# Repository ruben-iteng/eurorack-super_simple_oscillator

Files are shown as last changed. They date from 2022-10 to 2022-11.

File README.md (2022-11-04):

<div align="center">

# eurorack-super_simple_oscillator

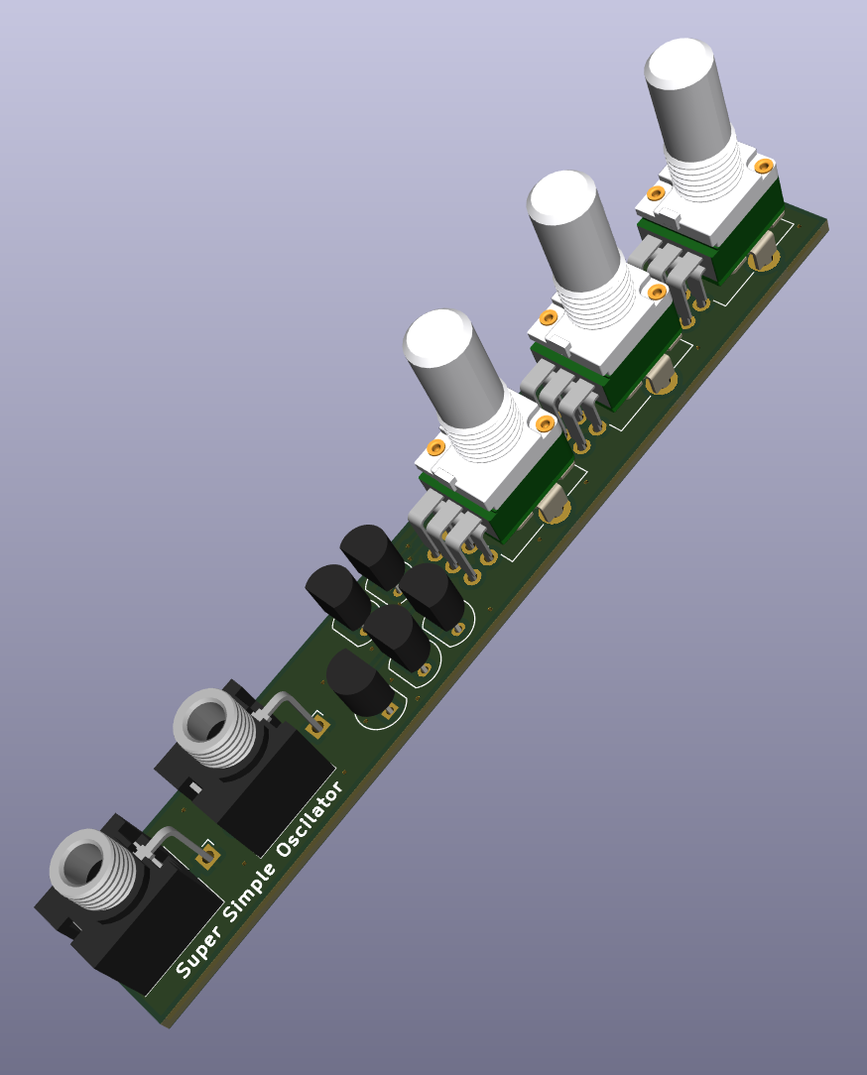
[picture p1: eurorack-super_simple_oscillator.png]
Super Simple Oscillator PCBA

<br/>

Eurorack modular synthesiser - Super Simple Oscillator

     

</div>

## About

<div align="center">
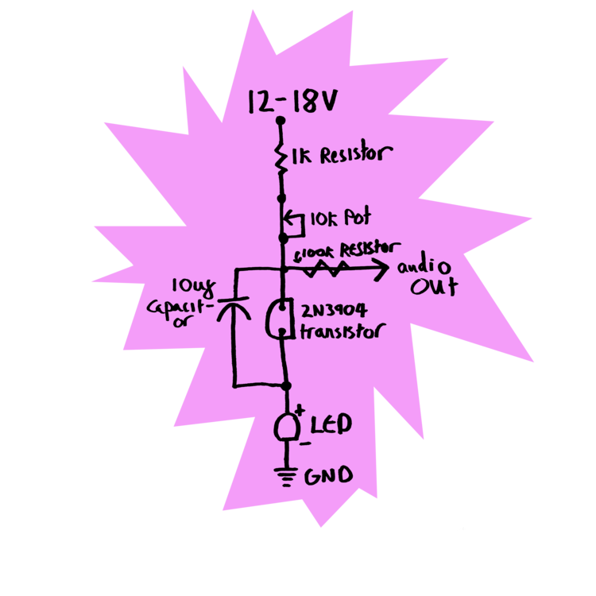
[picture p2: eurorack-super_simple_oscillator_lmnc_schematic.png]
SUPER SIMPLE OSCILLATOR SCHEMATIC, Look Mum No Computer, 05-2022

</div>

A super simple oscillator module (avalanche vco) in eurorack format based the designs of [Look Mum No Computer](https://www.lookmumnocomputer.com/projects#/simplest-oscillator) and [kassutronics](https://kassu2000.blogspot.com/2018/07/avalance-vco.html).
This project is build with the opensource EDA [faebryk](https://github.com/faebryk/faebryk).

## What can you do with this project?

You can use this project in various ways.
You can use it:

- as template for a faebryk project
- to build this VCO for your eurorack synth
- to design your own thing based on this design

## Working with the source files

See [here](./docs/development.md) for the instructions on how to install and edit this project.

## Building the SSO module

If you want to build a physical SSO eurorack module you can find the build instructions [here](./docs/build_instructions.md).

## Contibuting

If you want to share your alterations, improvements, or add bugfixes to this project, please take a look at the [contributing guidelines](./docs/CONTRIBUTING.md).

## Community Support

Community support is provided via Discord; see the Resources below for details.

### Resources

- Source Code: [https://github.com/ruben-iteng/eurorack-super_simple_oscillator](https://github.com/ruben-iteng/eurorack-super_simple_oscillator)
- Chat: Real-time chat happens in faebryk's Discord Server (chit-chat room for now). Use this Discord [Invite](https://discord.gg/95jYuPmnUW) to register
- Issues: [https://github.com/ruben-iteng/eurorack-super_simple_oscillator/issues](https://github.com/ruben-iteng/eurorack-super_simple_oscillator/issues)

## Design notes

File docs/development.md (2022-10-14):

# Working with the Super Simple Oscillator source

## Project structure

```markdown
📦eurorack-super_simple_oscillator
 ┣ 📂build `Here you can find the "usefull" files after building this project localy`
 ┃ ┣ 📂faebryk
 ┃ ┣ 📂kicad
 ┣ 📂docs `Project documentation is placed in this folder`
 ┣ 📂source
 ┃ ┣ 📂faebryk
 ┃ ┃ ┣ 📂library
 ┃ ┃ ┃ ┣ 📂library
 ┃ ┃ ┃ ┃ ┗ 📜components.py `In this file you can put the components that are not in the standard faebryk library`
 ┃ ┃ ┣ 📂modules
 ┃ ┃ ┗ 📜main.py `This is the main faberyk file of this project. Any changes should be made here`
 ┃ ┣ 📂kicad `KiCad project files`
 ┃ ┃ ┗ 📂main
 ┃ ┃ ┃ ┣ 📜main.kicad_pcb
 ┃ ┃ ┃ ┣ 📜main.kicad_pro
 ┃ ┃ ┃ ┣ 📜main.kicad_sch
 ┣ 📜.gitignore
 ┣ 📜eurorack-super_simple_oscillator.png
 ┣ 📜LICENSE
 ┣ 📜README.md `Project "homepage"`
 ┗ 📜requirements.txt `Required python/pip packages`
```

## Prerequisites

To start working on this project you will need the following.

### Step 1

Install the following programs:

- [Visual Code Studio](https://code.visualstudio.com/)
- [Python 3](https://www.python.org/) (add to PATH)
- [KiCad 6](https://www.kicad.org/)
- [git](https://git-scm.com/)

### Step 2

Clone this repository and install the requirements

```bash
git clone git@github.com:ruben-iteng/eurorack-super_simple_oscillator.git
```

```bash
cd eurorack-super_simple_oscillator
pip install -r requirements.txt
```

### Step 3

Run the project to see if everything is installed correctly

```bash
python3 ./source/main.py
```

This should output a netlist file in the `./build/faebryk/netlist/` folder.

### Step 4

Check if KiCad works

Open the `./source/kicad/main.prj` file in KiCad.

## Editing the project

The file you will work with most is the `./source/faebryk/main.py`. Here you describe your design in faebryk.

If you want to create your own components, traits or modules specific to this project you can place them in `./source/faebryk/library/<thing you want to add>`.

The PCB layout can be eddited in KiCad 6 by edditing the `./souce/kicad/main/main.kicad_pcb` file. If you changed anything in the faebryk source, you have to re-import the netlist into KiCad like so:

- `file > import > netlist`
- Select the file `./build/faebryk/faebryk.net`
- Press `Load and Test Netlist`
- If there are no errors, press `Update PCB`

## Running the project

To run the project and output the build files do as follow:

```bash
python ./source/faebryk/main.py
```

The output files will be in `./build/faebryk/`

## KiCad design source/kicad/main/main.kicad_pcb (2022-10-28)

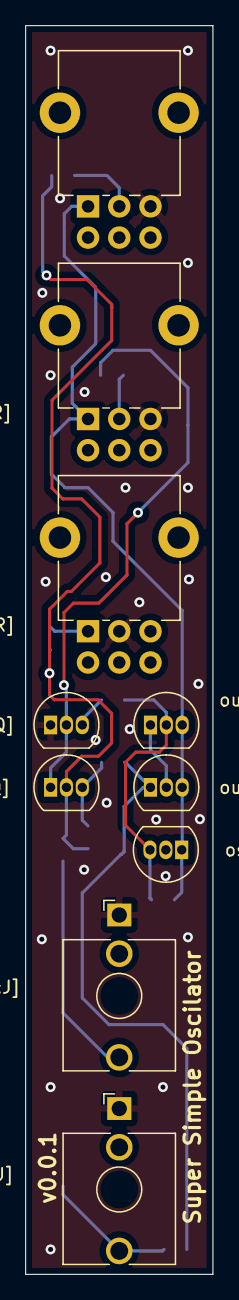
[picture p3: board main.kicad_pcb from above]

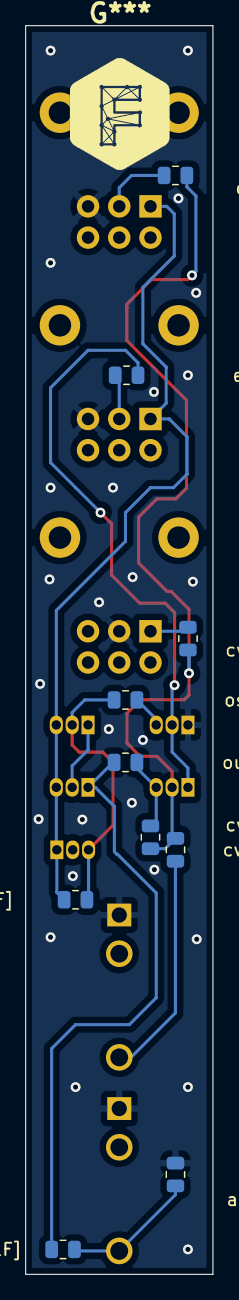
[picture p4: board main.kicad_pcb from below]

Board: 2 copper layers, 15.0 x 100.0 mm, 20 parts (10 on the bottom side), 14 nets.

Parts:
audio_output.ac_coupling_capacitor[Capacitor:9.999999999999998µF]: 9.999999999999998µF; R_0805_2012Metric
audio_output.jack[AudioJack2_Ground:J]: J; Jack_3.5mm_QingPu_WQP-PJ398SM_Vertical_CircularHoles
audio_output.pull_down_resistor[Resistor:10KΩ]: 10KΩ; R_0805_2012Metric
cv_input.freq_devider_mix_resistor[Resistor:150KΩ]: 150KΩ; R_0805_2012Metric
cv_input.frequency_control_potentiometer[Potentiometer:R], cv_input.voct_scale_trimmer[Potentiometer:R]: R; Potentiometer_Alpha_RD902F-40-00D_Dual_Vertical_CircularHol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
cv_input.input_impendace_resistor[Resistor:100KΩ]: 100KΩ; R_0805_2012Metric
cv_input.input_jack[AudioJack2_Ground:J]: J; Jack_3.5mm_QingPu_WQP-PJ398SM_Vertical_CircularHoles
cv_input.negative_bias_resistor[Resistor:220KΩ]: 220KΩ; R_0805_2012Metric
cv_input.voct_min_resistor[Resistor:1.0KΩ]: 1.0KΩ; R_0805_2012Metric
expo_converter.buffer[_2N3906:Q], expo_converter.current_sink[_2N3904:Q]: Q; TO-92_Inline
expo_converter.frequency_offset_current_min_resistor[Resistor:100KΩ]: 100KΩ; R_0805_2012Metric
expo_converter.frequency_offset_trimmer[Potentiometer:R]: R; Potentiometer_Alpha_RD902F-40-00D_Dual_Vertical_CircularHol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
osc_core.charge_capacitor[Capacitor:10.0µF]: 10.0µF; R_0805_2012Metric
osc_core.current_limiting_resistor[Resistor:1KΩ]: 1KΩ; R_0805_2012Metric
osc_core.reverse_avalanche_transistor[_2N3904:Q]: Q; TO-92_Inline
output_buffer.current_limiting_resistor[Resistor:10KΩ]: 10KΩ; R_0805_2012Metric
output_buffer.stages[0][_2N3904:Q], output_buffer.stages[1][_2N3904:Q]: Q; TO-92_Inline

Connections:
[Kassutronics_Avalance_VCO:virt]-cv_input[cv_input:virt]:2-cv_input.voct_scale_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: audio_output.jack[AudioJack2_Ground:J].S, audio_output.pull_down_resistor[Resisto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.2, cv_input.frequency_control_potentiomete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.3, cv_input.input_jack[AudioJack2_Ground:J].S, cv_input.voct_scale_trimmer[Potentiomet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.2, expo_converter.current_sink[_2N3904:Q].1, expo_converter.frequency_offset_trimmer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.3
[Kassutronics_Avalance_VCO:virt]:3-cv_input[cv_input:virt]:4-expo_converter[exp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: cv_input.negative_bias_resistor[Resisto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.2, expo_converter.buffer[_2N3906:Q].3, output_buffer.current_limiting_resistor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.2
audio_output.ac_coupling_capacitor[Capacitor:9.999999999999998µF]-audio_output.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: audio_output.ac_coupling_capacitor[Capa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.2, audio_output.jack[AudioJack2_Ground:J].T, audio_output.pull_down_resistor[Resisto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.1
audio_output[audio_output:virt]:2-output_buffer[output_buffer:virt]:3: audio_output.ac_coupling_capacitor[Capa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.1, output_buffer.current_limiting_resistor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.1, output_buffer.stages[1][_2N3904:Q].1
cv_input.frequency_control_potentiometer.resistors[0][Resistor:virt]-output_buf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: cv_input.frequency_control_potentiomete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.1, expo_converter.frequency_offset_trimmer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.1, osc_core.charge_capacitor[Capacitor:10.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.2, osc_core.reverse_avalanche_transistor[_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.1, output_buffer.stages[0][_2N3904:Q].3, output_buffer.stages[1][_2N3904:Q].3
cv_input.frequency_control_potentiometer.resistors[0][Resistor:virt]:2-cv_input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: cv_input.freq_devider_mix_resistor[Resi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.2, cv_input.frequency_control_potentiomete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.2
cv_input.input_jack[AudioJack2_Ground:J]-cv_input.input_impendace_resistor[Resi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: cv_input.input_impendace_resistor[Resis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.1, cv_input.input_jack[AudioJack2_Ground:J].T
cv_input.voct_scale_trimmer.resistors[0][Resistor:virt]: cv_input.voct_min_resistor[Resistor:1.0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.2, cv_input.voct_scale_trimmer[Potentiomet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.1
cv_input[cv_input:virt]-expo_converter[expo_converter:virt]: cv_input.freq_devider_mix_resistor[Resi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.1, cv_input.input_impendace_resistor[Resis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.2, cv_input.negative_bias_resistor[Resisto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.1, cv_input.voct_min_resistor[Resistor:1.0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.1, expo_converter.buffer[_2N3906:Q].2
expo_converter.frequency_offset_current_min_resistor[Resistor:100KΩ]-expo_conve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: expo_converter.buffer[_2N3906:Q].1, expo_converter.current_sink[_2N3904:Q].2, expo_converter.frequency_offset_current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.1
expo_converter.frequency_offset_trimmer.resistors[0][Resistor:virt]:2-expo_conv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: expo_converter.frequency_offset_current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.2, expo_converter.frequency_offset_trimmer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.2
osc_core[osc_core:virt]-expo_converter[expo_converter:virt]:2: expo_converter.current_sink[_2N3904:Q].3, osc_core.current_limiting_resistor[Resi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.1
osc_core[osc_core:virt]:3-output_buffer[output_buffer:virt]:4: osc_core.charge_capacitor[Capacitor:10.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.1, osc_core.current_limiting_resistor[Resi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.2, osc_core.reverse_avalanche_transistor[_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.3, output_buffer.stages[0][_2N3904:Q].2
output_buffer.stages[1][_2N3904:Q]-output_buffer.stages[0][_2N3904:Q]: output_buffer.stages[0][_2N3904:Q].1, output_buffer.stages[1][_2N3904:Q].2

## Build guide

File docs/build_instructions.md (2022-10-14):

# SSO build instructions

So you have decided to build the Super Simple Oscillator eurorack module but are questioning yourself, *"where should I start?"*.

You are in luck! :) You can start right here!

## Hardware

### PCB

The first step is to order the printed circuit boards (PCBs).

Most of the time a PCB manufacturer expexts a .zip file from you containing so called *gerber* files. These files are describing your PCB design in a way that it's understandable by the software the machines in the factory use.

The latest gerber file package can be found [here](https://github.com/ruben-iteng/eurorack-super_simple_oscillator/releases/latest) as `gerber.zip`.

See the `readme.md` file included in the realease package for specific order instructions.

Some common PCB manufacturers:

- [JLCPCB](https://jlcpcb.com/)
- [PCBWay](https://www.pcbway.com/)
- [Multi CB](https://www.multi-circuit-boards.eu/)
- [Eurocircuits](https://www.eurocircuits.com/)

### Components

The components you need can be ordered from different sources. Here are some suggestions:

- [Mouser](https://www.mouser.com/)
- [Digikey](https://www.digikey.com/)
- [Aliexpress](https://www.aliexpress.com/)
- [Thonk](https://www.thonk.co.uk/)

Some stores allow you to upload the `bom.csv` direcly, other you must search the components manually.

### Assembly

TBD

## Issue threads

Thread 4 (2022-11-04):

Rename or place renamed components on PCB again

ruben-iteng, 2022-11-04:
_2N3904, _2N3906 and AudioJack2_GroundFP have different type_descriptions now, so will need to be placed again in pcb, see: https://github.com/ruben-iteng/eurorack-super_simple_oscillator/pull/3#issuecomment-1295140317

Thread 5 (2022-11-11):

Old faebryk sample description in source file

ruben-iteng, 2022-11-11:
https://github.com/ruben-iteng/eurorack-super_simple_oscillator/blob/fe5398f95219f458deac16fb34f104d0d03a6ea9/source/faebryk/main.py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

Replace with this project description

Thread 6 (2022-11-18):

Missing power input

ruben-iteng, 2022-11-18:
There is no power connector..

Use a keyed 2x5 IDC connector

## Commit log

2022-10-14 Bring up to working state
    - Add KiCad source files
    - Add KiCad files to gitignore
    - Fix component import
    - Fix typo in readme
    - Fix: make it run
    - Fix markdown rendering issue
    - Fix issues preventing running
    - Fix: has_defined_type_description
    - Fix: has_defined_footprint
    - Fix: expo_converter: wrong connections
    - Fix: missing pinmap frequency_offset_trimmer
    - Fix missing potentiometer resistance values
    - Fix audio_output: wrong connections
    - Update and add documentation
    [main.kicad_pcb, main.kicad_sch]
2022-10-28 Merge pull request #1 from feature/update_for_faebryk_release
    * Add PCB image
    * Prepare for new faebryk release
    - fix wrong connections
    - fix wrong resistor values
    - add missing pot
    - remove add_all function from local lib
    * Fix image overlay text
    * Fix: remove unnecessary pip requirements
    * Fix netlist import from faebryk
    [main.kicad_pcb]
2022-11-04 Adapt CMPs and IFs to newest faebryk api (#3)
    Reload kicad converted libs

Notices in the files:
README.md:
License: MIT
